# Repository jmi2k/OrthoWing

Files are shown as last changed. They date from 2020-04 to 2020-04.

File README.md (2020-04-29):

OrthoWing
=========

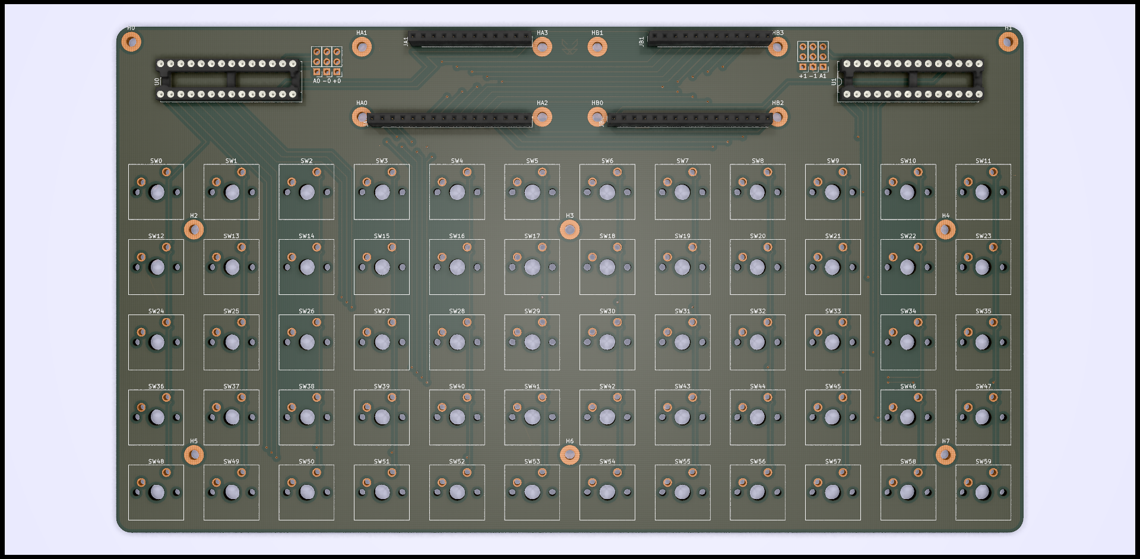
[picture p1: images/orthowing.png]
Render


- **dimensions**: 229.87mm × 128.27mm
- **layers**: 2

This is a Feather-compatible keyboard. It has a 5×12 ortholinear layout which
makes it very portable and a good fit for exotic use-cases (such as
macro-keyboards). The holes are designed for Cherry MX-compatible switches,
with no extra features.

Usage
-----

Both Feather sockets are interconnected, just like [Adafruit's FeatherWing
Doubler](https://www.adafruit.com/products/2890). The chip sockets hold two
MCP23017 I/O expanders, one on the left to select the column and one on the
right to get the keys pressed on each row for that column.

A controller Feather must also be attached, which scan the key matrix using
these two expanders through I²C. With the help of the second socket and
stacking headers, lots of FeatherWings can be added to provide additional
features!

Use cases
---------

Given a suitable controller (like this [Adafruit Feather
32u4](https://www.adafruit.com/product/2771)), it can be a regular USB
keyboard!

If you want something more exotic, I encourage you to try to push the limits
of the Feather interface! There are compatible displays, sensors, wireless
transceivers, even [quite powerful
FPGAs](https://github.com/gregdavill/OrangeCrab). The keyboard itself doesn't
use any GPIO pins, just the I²C pins (which are shared among all devices
attached), so these are all free.

License
-------

This project is licensed under the [Creative Commons Attribution-ShareAlike
4.0 International License](http://creativecommons.org/licenses/by-sa/4.0/).

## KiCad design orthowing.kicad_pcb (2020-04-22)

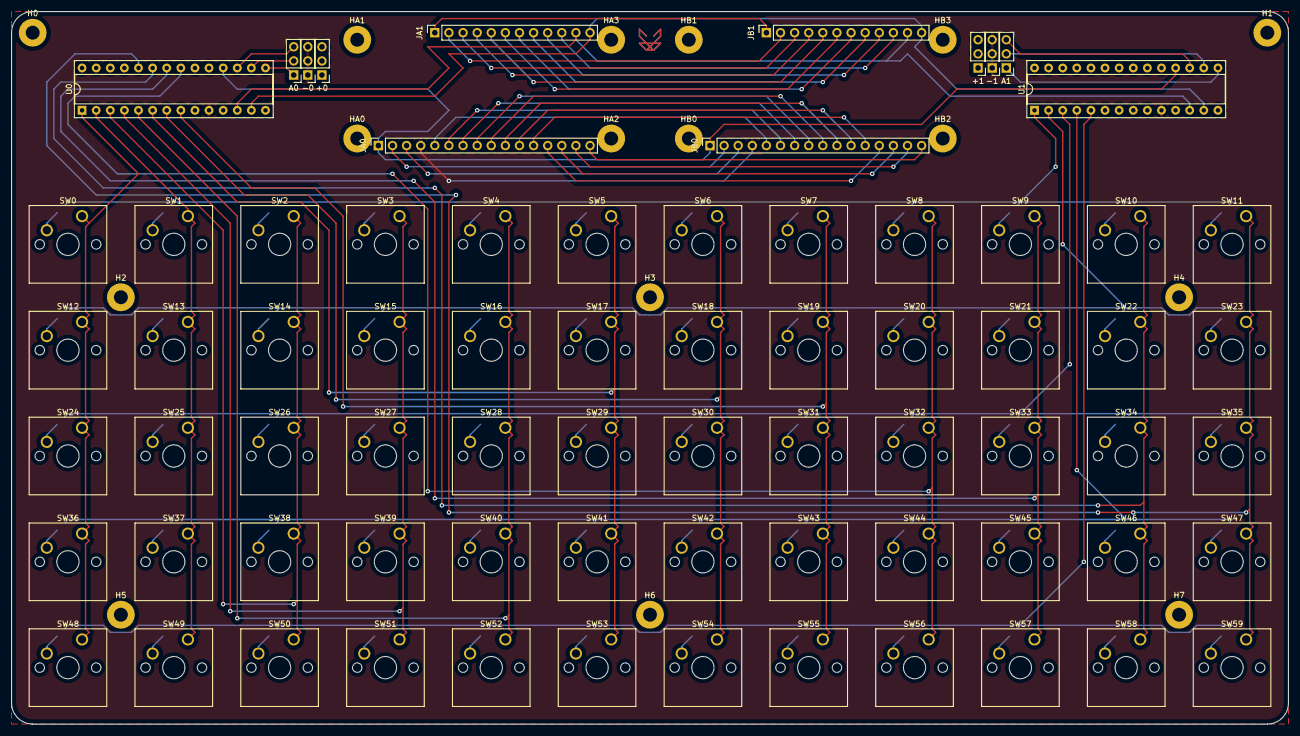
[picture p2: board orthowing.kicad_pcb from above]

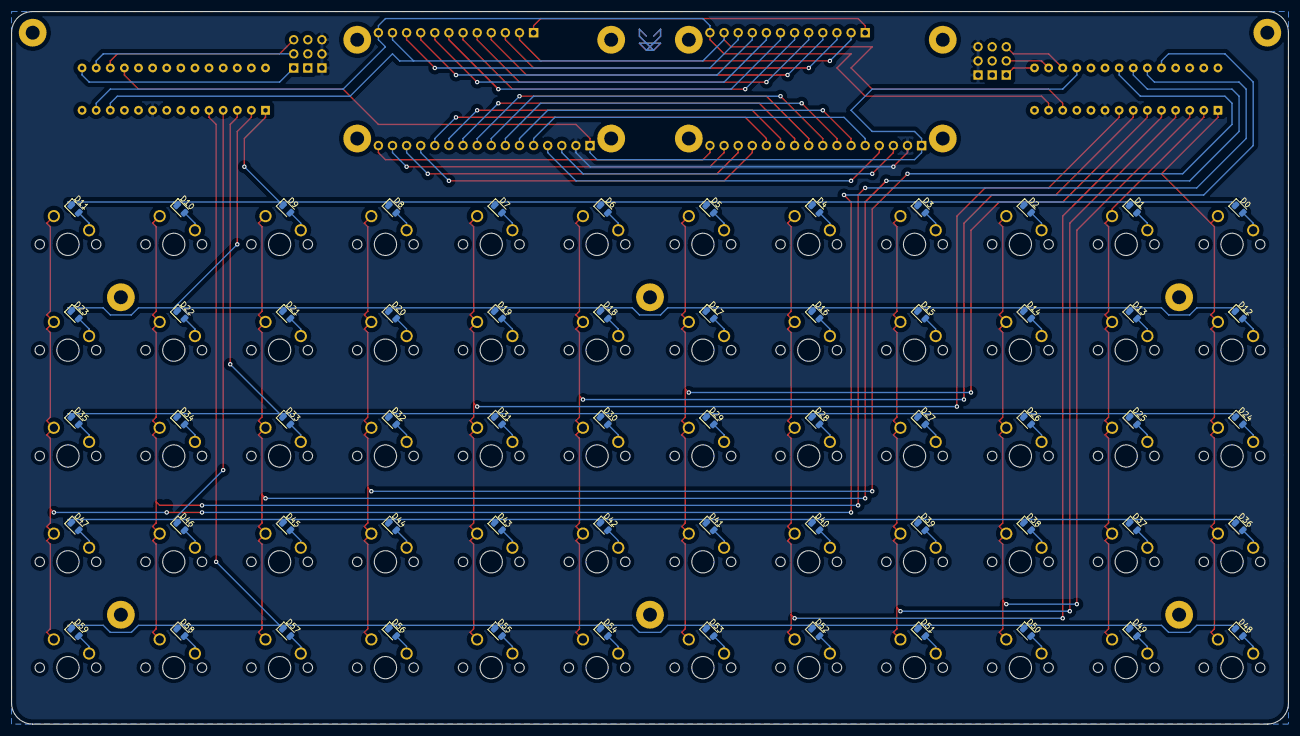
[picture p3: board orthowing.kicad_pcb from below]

Board: 2 copper layers, 229.9 x 128.3 mm, 148 parts (60 on the bottom side), 111 nets.

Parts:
+0, +1: Conn_01x03; PinHeader_1x03_P2.54mm_Vertical
-0, -1: Conn_01x03; PinHeader_1x03_P2.54mm_Vertical
A0, A1: Conn_01x03; PinHeader_1x03_P2.54mm_Vertical
D0, D1, D2, D3, D4, D5, D6, D7, D8, D9, D10, D11, D12, D13, D14, D15, D16, D17, D18, D19, D20, D21, D22, D23, D24, D25, D26, D27, D28, D29, D30, D31, D32, D33, D34, D35, D36, D37, D38, D39, D40, D41, D42, D43, D44, D45, D46, D47, D48, D49, D50, D51, D52, D53, D54, D55, D56, D57, D58, D59: D; D_0805_2012Metric
H0, H1, H2, H3, H4, H5, H6, H7: MountingHole; MountingHole_2.5mm_Pad
HA0, HA1, HA2, HA3: MountingHole; MountingHole_2.5mm_Pad
HB0, HB1, HB2, HB3: MountingHole; MountingHole_2.5mm_Pad
JA0: Conn_01x16_Female; PinSocket_1x16_P2.54mm_Vertical
JA1: Conn_01x12_Female; PinSocket_1x12_P2.54mm_Vertical
JB0: Conn_01x16_Female; PinSocket_1x16_P2.54mm_Vertical
JB1: Conn_01x12_Female; PinSocket_1x12_P2.54mm_Vertical
SW0, SW1, SW2, SW3, SW4, SW5, SW6, SW7, SW8, SW9, SW10, SW11, SW12, SW13, SW14, SW15, SW16, SW17, SW18, SW19, SW20, SW21, SW22, SW23, SW24, SW25, SW26, SW27, SW28, SW29, SW30, SW31, SW32, SW33, SW34, SW35, SW36, SW37, SW38, SW39, SW40, SW41, SW42, SW43, SW44, SW45, SW46, SW47, SW48, SW49, SW50, SW51, SW52, SW53, SW54, SW55, SW56, SW57, SW58, SW59: SW_MX; SW_Cherry_MX1A_1.00u_PCB
U0, U1: MCP23017_SP; DIP-28_W7.62mm_Socket

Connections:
0: JA0.14, JB0.14
1: JA0.15, JB0.15
3V3: +0.1, +0.2, +0.3, +1.1, +1.2, +1.3, JA0.2, JB0.2, U0.9, U1.9
5: JA1.10, JB1.10
6: JA1.9, JB1.9
9: JA1.8, JB1.8
10: JA1.7, JB1.7
11: JA1.6, JB1.6
12: JA1.5, JB1.5
13: JA1.4, JB1.4
A0: JA0.5, JB0.5
A1: JA0.6, JB0.6
A2: JA0.7, JB0.7
A3: JA0.8, JB0.8
A4: JA0.9, JB0.9
A5: JA0.10, JB0.10
AREF: JA0.3, JB0.3
C0: SW0.1, SW12.1, SW24.1, SW36.1, SW48.1, U0.1
C1: SW1.1, SW13.1, SW25.1, SW37.1, SW49.1, U0.2
C2: SW2.1, SW14.1, SW26.1, SW38.1, SW50.1, U0.3
C3: SW3.1, SW15.1, SW27.1, SW39.1, SW51.1, U0.4
C4: SW4.1, SW16.1, SW28.1, SW40.1, SW52.1, U0.5
C5: SW5.1, SW17.1, SW29.1, SW41.1, SW53.1, U0.6
C6: SW6.1, SW18.1, SW30.1, SW42.1, SW54.1, U0.7
C7: SW7.1, SW19.1, SW31.1, SW43.1, SW55.1, U0.8
C8: SW8.1, SW20.1, SW32.1, SW44.1, SW56.1, U0.21
C9: SW9.1, SW21.1, SW33.1, SW45.1, SW57.1, U0.22
C10: SW10.1, SW22.1, SW34.1, SW46.1, SW58.1, U0.23
C11: SW11.1, SW23.1, SW35.1, SW47.1, SW59.1, U0.24
EN: JA1.2, JB1.2
GND: -0.1, -0.2, -0.3, -1.1, -1.2, -1.3, JA0.4, JB0.4, U0.10, U1.10
MISO: JA0.13, JB0.13
MOSI: JA0.12, JB0.12
unnamed: A0.1, U0.15
unnamed: A0.2, U0.16
unnamed: A0.3, U0.17
unnamed: A1.1, U1.15
unnamed: A1.2, U1.16
unnamed: A1.3, U1.17
unnamed: D0.2, SW0.2
unnamed: D1.2, SW1.2
unnamed: D2.2, SW2.2
unnamed: D3.2, SW3.2
unnamed: D4.2, SW4.2
unnamed: D5.2, SW5.2
unnamed: D6.2, SW6.2
unnamed: D7.2, SW7.2
unnamed: D8.2, SW8.2
unnamed: D9.2, SW9.2
unnamed: D10.2, SW10.2
unnamed: D11.2, SW11.2
unnamed: D12.2, SW12.2
unnamed: D13.2, SW13.2
unnamed: D14.2, SW14.2
unnamed: D15.2, SW15.2
unnamed: D16.2, SW16.2
unnamed: D17.2, SW17.2
unnamed: D18.2, SW18.2
unnamed: D19.2, SW19.2
unnamed: D20.2, SW20.2
unnamed: D21.2, SW21.2
unnamed: D22.2, SW22.2
unnamed: D23.2, SW23.2
unnamed: D24.2, SW24.2
unnamed: D25.2, SW25.2
unnamed: D26.2, SW26.2
unnamed: D27.2, SW27.2
unnamed: D28.2, SW28.2
unnamed: D29.2, SW29.2
unnamed: D30.2, SW30.2
unnamed: D31.2, SW31.2
unnamed: D32.2, SW32.2
unnamed: D33.2, SW33.2
unnamed: D34.2, SW34.2
unnamed: D35.2, SW35.2
unnamed: D36.2, SW36.2
unnamed: D37.2, SW37.2
unnamed: D38.2, SW38.2
unnamed: D39.2, SW39.2
unnamed: D40.2, SW40.2
unnamed: D41.2, SW41.2
unnamed: D42.2, SW42.2
unnamed: D43.2, SW43.2
unnamed: D44.2, SW44.2
unnamed: D45.2, SW45.2
unnamed: D46.2, SW46.2
unnamed: D47.2, SW47.2
unnamed: D48.2, SW48.2
unnamed: D49.2, SW49.2
unnamed: D50.2, SW50.2
unnamed: D51.2, SW51.2
unnamed: D52.2, SW52.2
unnamed: D53.2, SW53.2
unnamed: D54.2, SW54.2
unnamed: D55.2, SW55.2
unnamed: D56.2, SW56.2
unnamed: D57.2, SW57.2
unnamed: D58.2, SW58.2
unnamed: D59.2, SW59.2
R0: D0.1, D1.1, D2.1, D3.1, D4.1, D5.1, D6.1, D7.1, D8.1, D9.1, D10.1, D11.1, U1.1
R1: D12.1, D13.1, D14.1, D15.1, D16.1, D17.1, D18.1, D19.1, D20.1, D21.1, D22.1, D23.1, U1.2
R2: D24.1, D25.1, D26.1, D27.1, D28.1, D29.1, D30.1, D31.1, D32.1, D33.1, D34.1, D35.1, U1.3
R3: D36.1, D37.1, D38.1, D39.1, D40.1, D41.1, D42.1, D43.1, D44.1, D45.1, D46.1, D47.1, U1.4
R4: D48.1, D49.1, D50.1, D51.1, D52.1, D53.1, D54.1, D55.1, D56.1, D57.1, D58.1, D59.1, U1.5
RST: JA0.1, JB0.1, U0.18, U1.18
SCK: JA0.11, JB0.11
SCL: JA1.11, JB1.11, U0.12, U1.12
SDA: JA1.12, JB1.12, U0.13, U1.13
VBAT: JA1.1, JB1.1
VUSB: JA1.3, JB1.3
X: JA0.16, JB0.16

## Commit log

2020-04-22 Upload to GitHub
    [fileIO.sch, fileKeys.sch, fileSockets.sch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]
2020-04-29 Remove 'keyswitches.pretty' submodule
    Apparently, I wasn't even using it in the first place, as KiCad already
    includes a mechanical switch library. I chose one of them by mistake, but it
    turned out to be an useful mistake.
